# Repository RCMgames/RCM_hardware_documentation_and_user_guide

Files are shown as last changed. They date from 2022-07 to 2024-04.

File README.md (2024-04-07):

RCM User Guide: documentation of the pinout of the RCM board.

Robot Control Module: instructions and CAD for the original 3 versions of RCM boards.

## RCM_ORIGINAL

power with 5 NiMH AA batteries



[new robot code](https://github.com/RCMgames/RCMv2)

[new driver station](https://github.com/RCMgames/RCMDS-new)

[old robot code](https://github.com/RCMgames/RCM)

[old driverstation](https://github.com/RCMgames/RCMDS)

See https://github.com/RCMgames/RCM-Hardware-BYTE and https://github.com/RCMgames/RCM-Hardware-Nibble for more advanced Robot Control Modules.

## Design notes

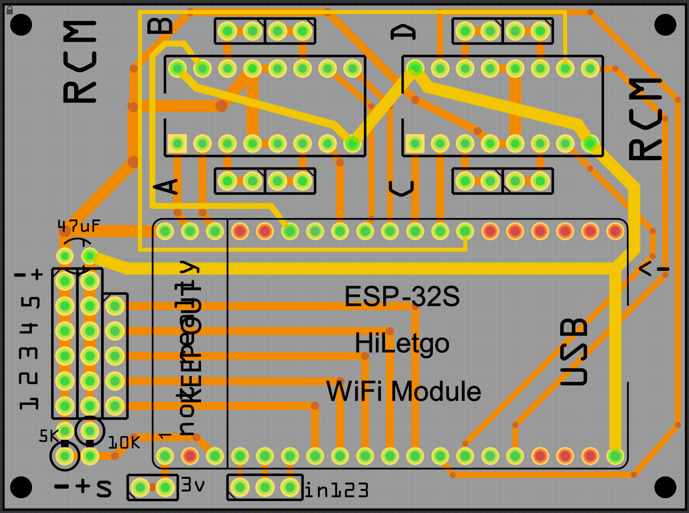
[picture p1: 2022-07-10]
Robot Control Module/V3/circuit diagram and fritzing design/images/image.png

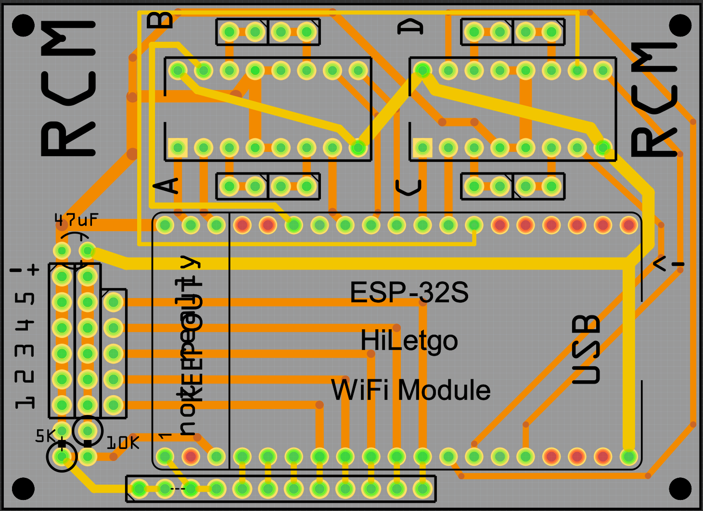
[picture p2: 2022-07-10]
Robot Control Module/V3/circuit diagram and fritzing design/images/Screenshot 2021-02-08 134622.png

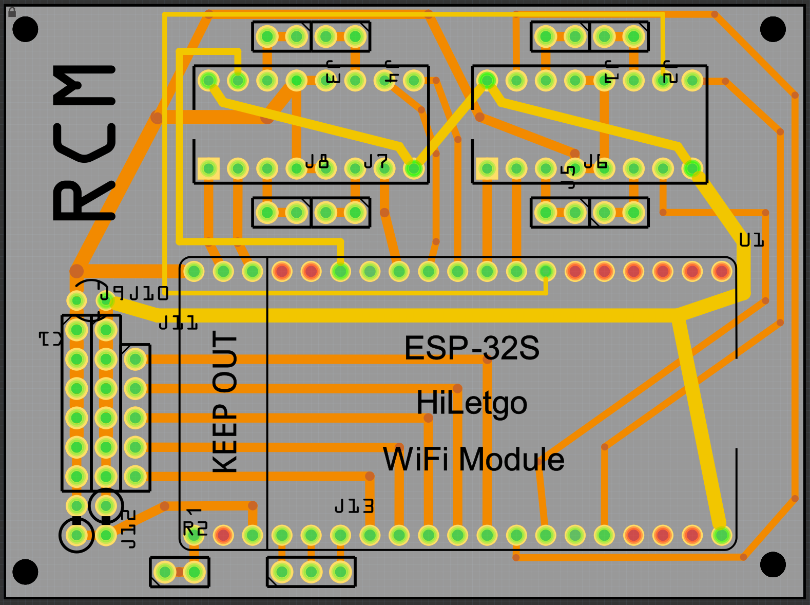
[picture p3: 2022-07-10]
Robot Control Module/V3/circuit diagram and fritzing design/images/Screenshot 2021-02-08 115525.png

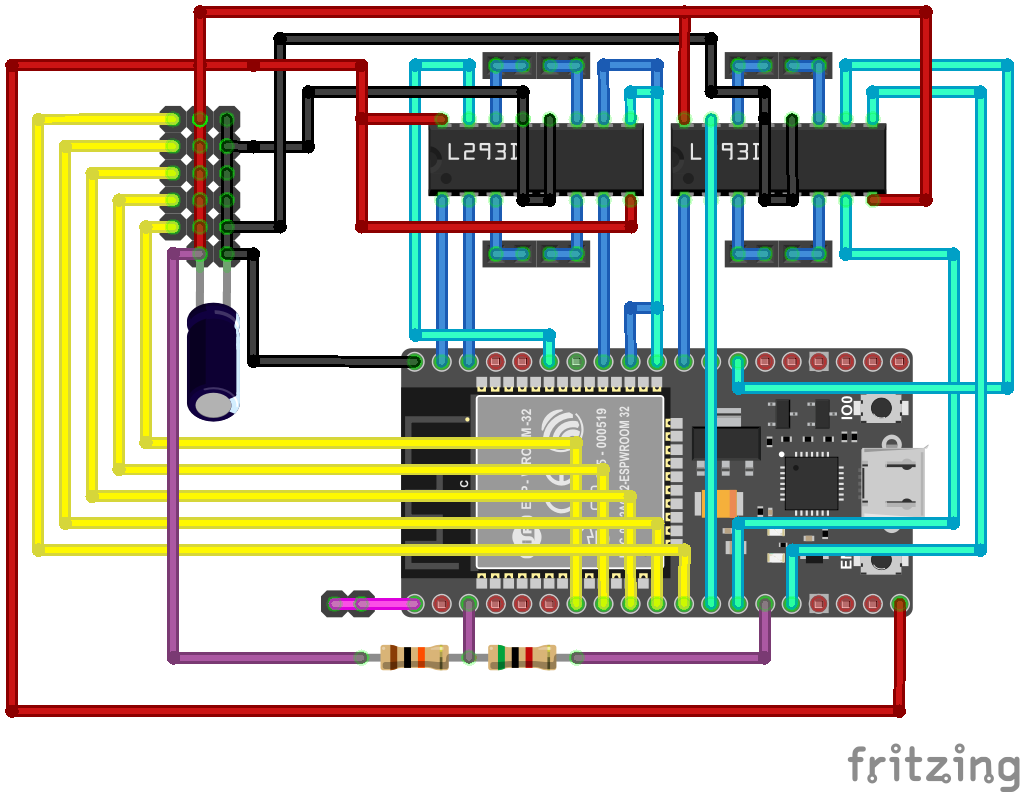
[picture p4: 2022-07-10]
Robot Control Module/V3/circuit diagram and fritzing design/rcm_bb.png

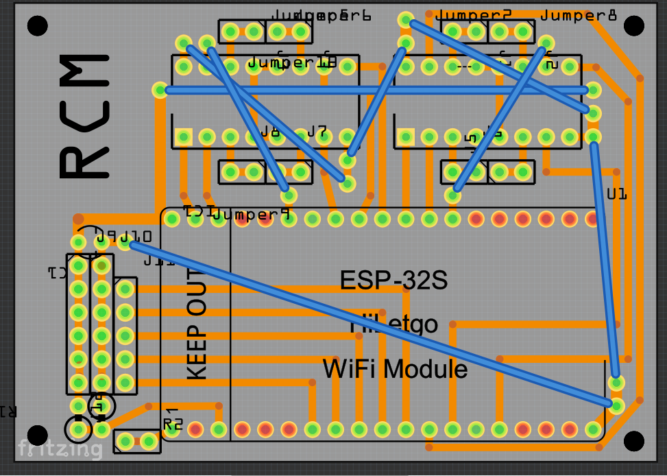
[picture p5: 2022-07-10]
Robot Control Module/other documents/Screenshot 2021-07-22 152102.png

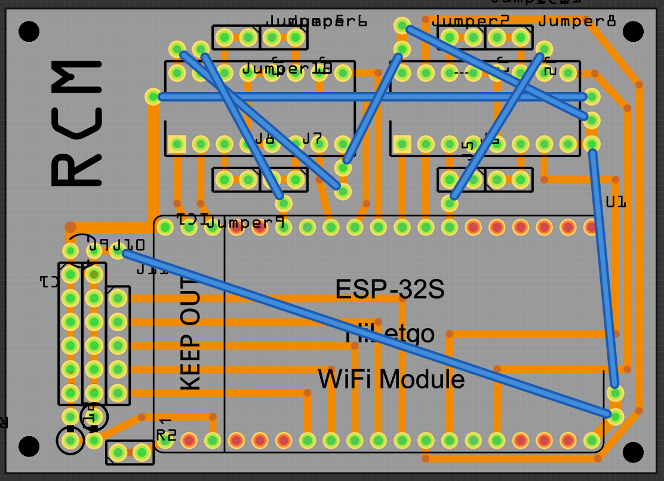
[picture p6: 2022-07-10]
Robot Control Module/other documents/Capture.PNG

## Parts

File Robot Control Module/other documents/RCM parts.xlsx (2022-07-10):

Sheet: parts
Parts for RCM | Part | description | pkg price | enough for | link | alternatives
 | esp32 | processor + wifi | $10.99 | 1 | https://www.amazon.com/dp/B0718T232Z (https://www.amazon.com/HiLetgo-ESP-WROOM-32-Development-Microcontroller-Integrated/dp/B0718T232Z?s=electronics) | 2 for $15 https://www.amazon.com/dp/B07QCP2451
 | L293D | motor driver chip | $7.94 | 5 | https://www.amazon.com/dp/B07BV5R2FY (https://www.amazon.com/Luckkyme-Stepper-Drivers-Controllers-Control/dp/B07BV5R2FY?s=electronics)
 | perf board | hold the parts | $7.99 | 20 | https://www.amazon.com/dp/B07XYL451Y (https://www.amazon.com/AiTrip-Perfboard-Breadboard-Prototyping-Electronic/dp/B07XYL451Y?s=industrial) | custom PCB
 | headers | external ports | $5.99 | 8 | https://www.amazon.com/dp/B074HVBTZ4/
 | 16pin IC sockets | l293d socket
 | wire | 22 gauge or thicker solid core wire recommended | $7.99 | >~5 | https://www.amazon.com/dp/B08979VWP5 (https://www.amazon.com/NorthPada-Electronic-Electrical-Tinned-Voltage/dp/B08979VWP5?s=industrial)
 | capacitors | for esp32 regulator | $5.58 | 10 | https://www.amazon.com/dp/B07KPWC3PB
 | 5K and 10K resistor |  | 8 | 20 | https://www.amazon.com/dp/B0792M83JH
Parts required for a robot
 | power switch |  | $5.99 | 16 | https://www.amazon.com/dp/B0817QGXL2 (https://www.amazon.com/Jabinco-Solder-Rocker-Switch-Toggle/dp/B0817QGXL2)
 | 5 AA battery holder |  | $7.99 | 2 | https://www.amazon.com/dp/B07WRQ44YK
 | 5 NiMH AA batteries
 | battery charger
 | micro usb cable | for programming
----------------------------------------------------------------------------------------------------------------------------------------------------------------------------------------------------------------------------------------------------------------------------------------------------------------------------------------------------------------------------------------------------
 | part type | specific part | pkg price | quantity | link
Misc
 | servo extension cable | jumper wires | $6.98 | 26 | https://www.amazon.com/gp/product/B01EV70C78
Actuators
 | motors
 |  | geared motors with wheels | $14.99 | 4 | https://www.amazon.com/dp/B07DQGX369
 | absolute position servos
 |  | micro servo | $7.99 | 2 | https://www.amazon.com/dp/B07NKRLL5C (https://www.amazon.com/DGZZI-Micro-Replacement-Helicopter-Airplane/dp/B07NKRLL5C?s=toys-and-games)
 |  | medium servo | $15.89 | 2 | https://www.amazon.com/dp/B0881W548Z (https://www.amazon.com/Youleke-MG996R-Metal-Torque-Digital/dp/B0881W548Z?s=toys-and-games)
 | continuous rotation servos
 |  | 9g servo | $13.79 | 2 | https://www.amazon.com/dp/B086ZGTLZB (https://www.amazon.com/Feetech-Continuous-Rotation-Arduino-Microbit/dp/B086ZGTLZB?s=toys-and-games)
Hardware
 | ball casters |  | $9.89 | 6 | https://www.amazon.com/dp/B07HC3Z56Z (https://www.amazon.com/DGQ-Transfers-Furniture-Trolley-Mounted/dp/B07HC3Z56Z)
 | omni wheels |  | $6.84 | 1 | https://www.robotshop.com/en/58mm-plastic-omni-wheel-compatible-servos-lego-mindstorms-nxt.html
 | mechanum wheels |  | $28.59 | 4 | https://www.amazon.com/dp/B082WY3M8G (https://www.amazon.com/Hideness-Mecanum-Connector-Raspberry-Microbit/dp/B082WY3M8G)
 | Makeblock parts are amazing! they have 4mm ID 8mm OD barrings and other things that are helpful if you don't mind trading speed/weight for design complexity
Sensors
 | IR proximity sensors |  | $5.39 | 5 | https://www.amazon.com/dp/B00XAGSWR4
 | limit switches
Gamepieces
 | mini powerup | 1" wooden cubes | $15.99 | 120 | https://www.amazon.com/dp/B072VZFYFC (https://www.amazon.com/Supla-120pcs-Natural-Wooden-Unfinished/dp/B072VZFYFC)

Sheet: Copy of parts
part | description | num needed |  | pkg price | num in pkg | link |  | pkg price | num in pkg | link | <amazon links
esp32 | processor + wifi | 1 | $4.52 | $4.52 | 1 | https://www.aliexpress.com/item/32858054775.html | $8.00 | $15.99 | 2 | https://www.amazon.com/dp/B07QCP2451/
L293D | motor driver chip | 2 | $0.30 | $1.48 | 10 | https://www.aliexpress.com/item/32260501846.html | $1.80 | $8.99 | 10 | https://www.amazon.com/dp/B00ODQM8KC
perf board | hold the parts | 1 | $0.16 | $3.15 | 20 | https://www.aliexpress.com/item/4000742310134.html | $0.47 | $9.50 | 20 | https://www.amazon.com/dp/B072Q1H6GX/
male headers | external ports | 35 | $0.17 | $1.90 | 400 | https://www.aliexpress.com/item/32724478308.html | $0.35 | $5.99 | 600 | https://www.amazon.com/dp/B074HVBTZ4/
female headers | plug for esp32, regulator, capacitors | 49 |  | " | 400 | " | $0.35 | " | 600 | "
16pin IC sockets | l293d socket | 2 | $0.12 | $2.94 | 50 | https://www.aliexpress.com/item/32344551607.html | $0.40 | $5.99 | 30 | https://www.amazon.com/dp/B0079SM1LW/
3d printed shell |  |  |  | - | -
wire |  |  |  | - | -
5 AA bat holder |  | 1 | $1.63 | $1.63 | 1 | https://www.aliexpress.com/item/4000105309247.html | $3.50 | $6.99 | 2 | https://www.amazon.com/dp/B07WRQ44YK
capacitors | for esp32 regulator | 1 | $0.04 | $2.17 | 50 | https://www.aliexpress.com/item/32911921657.html | $0.56 | $5.58 | 10 | https://www.amazon.com/dp/B07KPWC3PB
drive motors | geared motors with wheels | 2 | $2.25 | $4.51 | 4 | https://www.aliexpress.com/item/4000126948489.html | $7.50 | $14.99 | 4 | https://www.amazon.com/dp/B07DQGX369
servos |  | 2 | $2.12 | $10.60 | 10 | https://www.aliexpress.com/item/33009883276.html | $3.80 | $18.99 | 10 | https://www.amazon.com/dp/B072V529YD
5K resistor |  | 1
10K resistor |  | 1
 |  |  | $11.31 |  |  |  | $26.71

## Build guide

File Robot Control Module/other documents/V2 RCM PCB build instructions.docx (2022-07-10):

# Build Instructions for Robot Control Module

Using an ESP-32 processor and L293D motor driver chips

# Design:

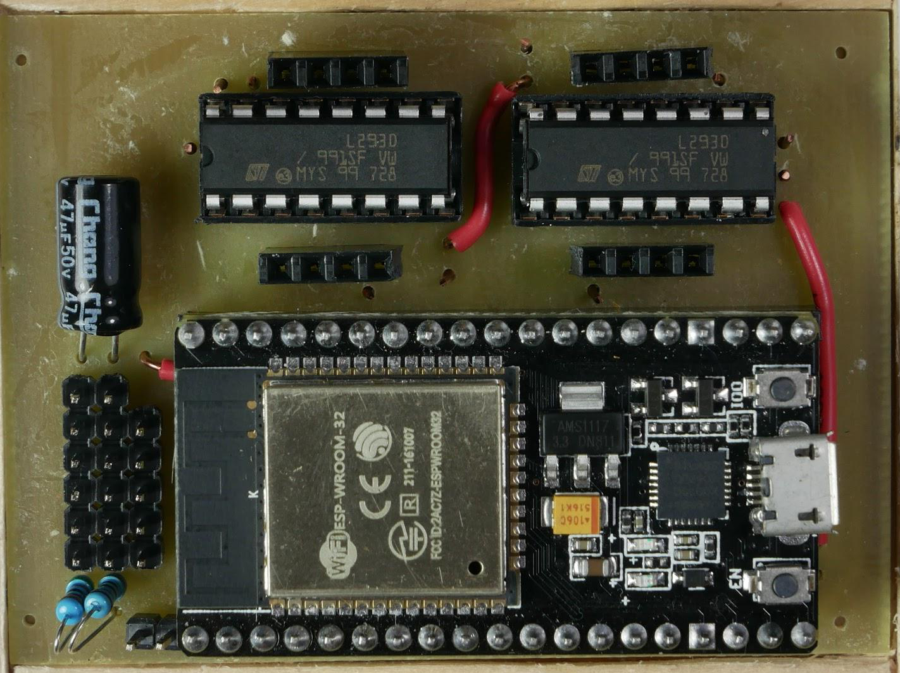
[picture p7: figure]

Top view of finished board

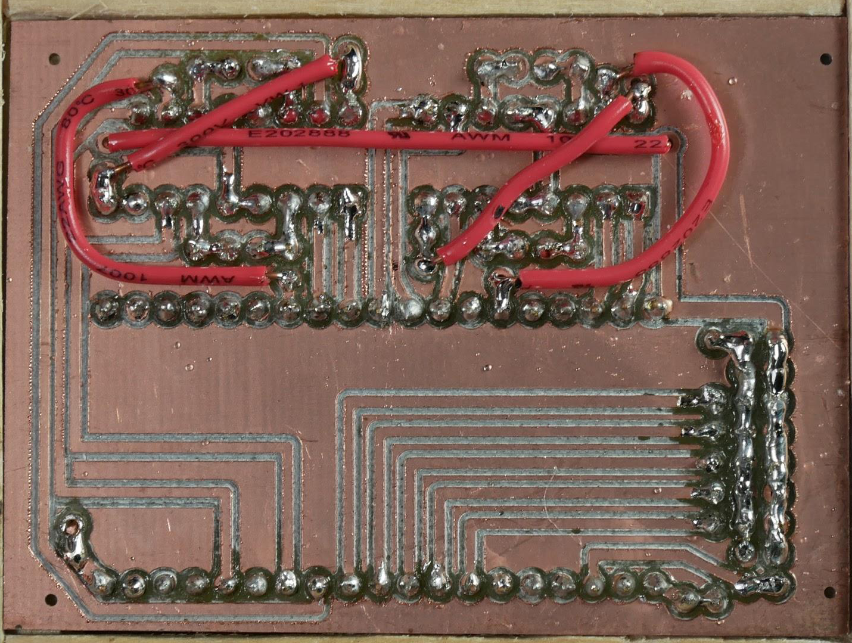
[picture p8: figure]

Bottom view of finished board (flipped like turning a page)


This picture shows the connections of the board. This is a top view of the board but shows the traces as if the board were see through.

# Parts:

1 NodeMCU ESP-32s, it should have 38 pins

2 L293D motor driver chip

1 custom circuit board

56 female header pins

19 male header pins

2 16 pin IC sockets

4ft wire (I used 22 gauge solid core)

1 5 AA bat holder

1 47uf capacitor

1 5 KΩ resistor

1 10 KΩ resistor

0-4 small 6v geared motors (<600 mA)

0-5 micro servo motors

5 rechargeable NiMH AA batteries

# Tools:

Soldering iron

Solder

Needle nose pliers

Wire strippers

Flush cutters

Sandpaper

Fume extractor fan

Tape

# Custom Circuit Board:

Here is the fritzing file for the board: https://drive.google.com/open?id=1aipQb9t6Qfr8hrADWvjOZhG9OkPFuLrj

When exporting for your router or circuit board service, make sure that the board will end up like in the photo below and not mirrored or with the traces on the wrong side of the board.

# Build:

Check the metal side of the board and make sure there are no shorts across traces or “stringy” bits of metal.

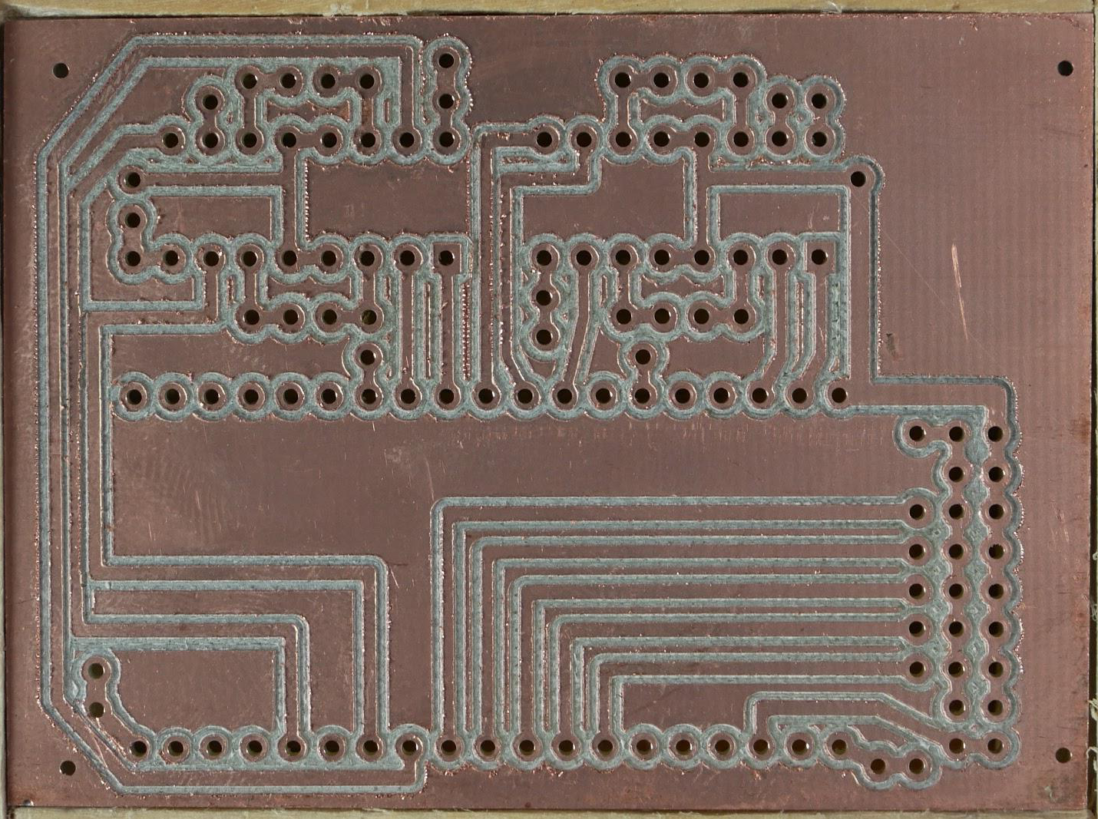
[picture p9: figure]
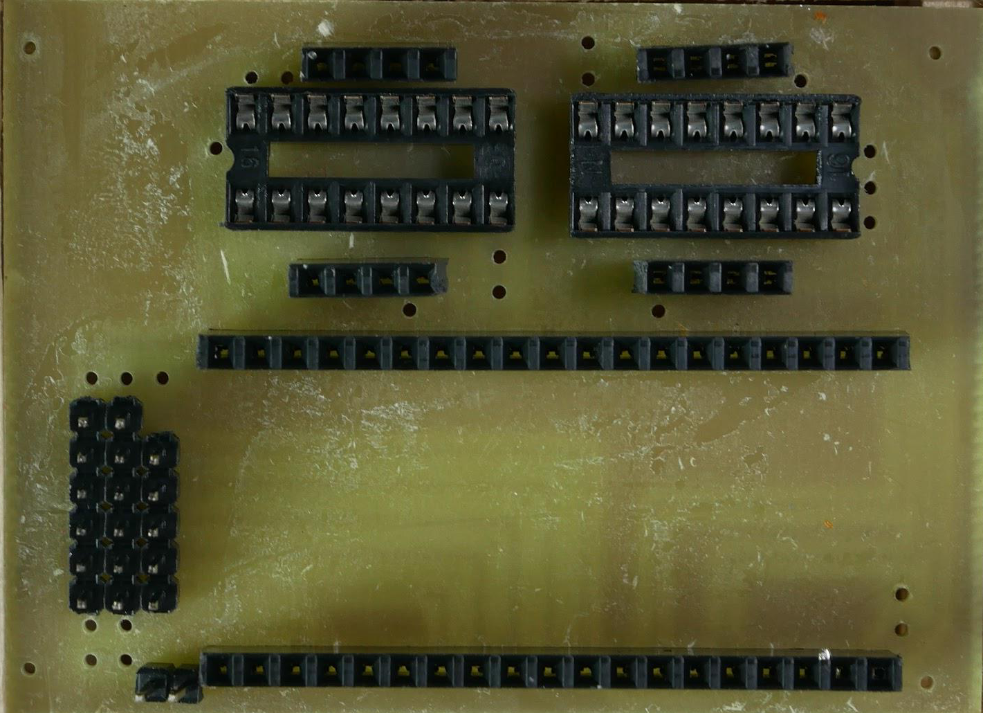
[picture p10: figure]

Place components in the board as shown.

Use tape to secure each part to the board so it won’t fall out when you turn the board over to solder. Make sure everything stays at right angles to the board since if pins are soldered at an angle it will be hard to plug into them later.

Solder every pin to the board.

If two pins get bridged by solder that aren’t connected with a copper trace, you need to disconnect them (try melting the bridge with the soldering iron and “cutting” the blob with the tip of the iron.

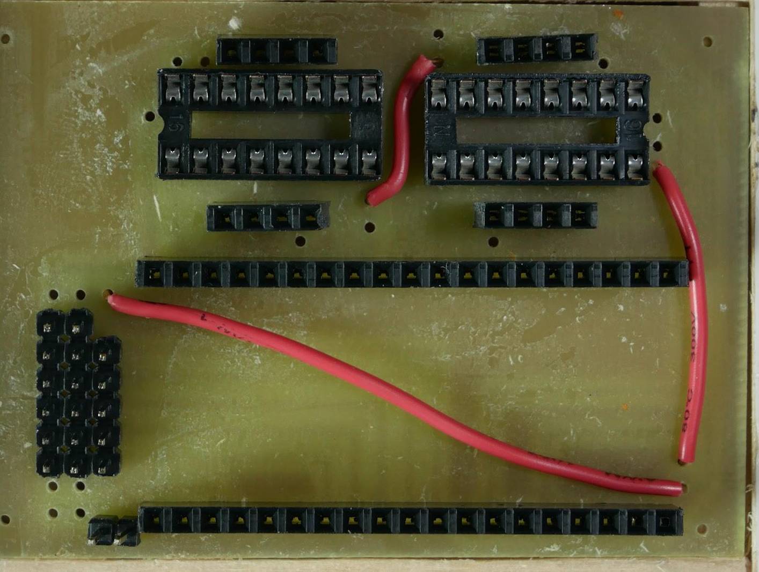
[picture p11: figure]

Add three wires to the top of the board as shown.

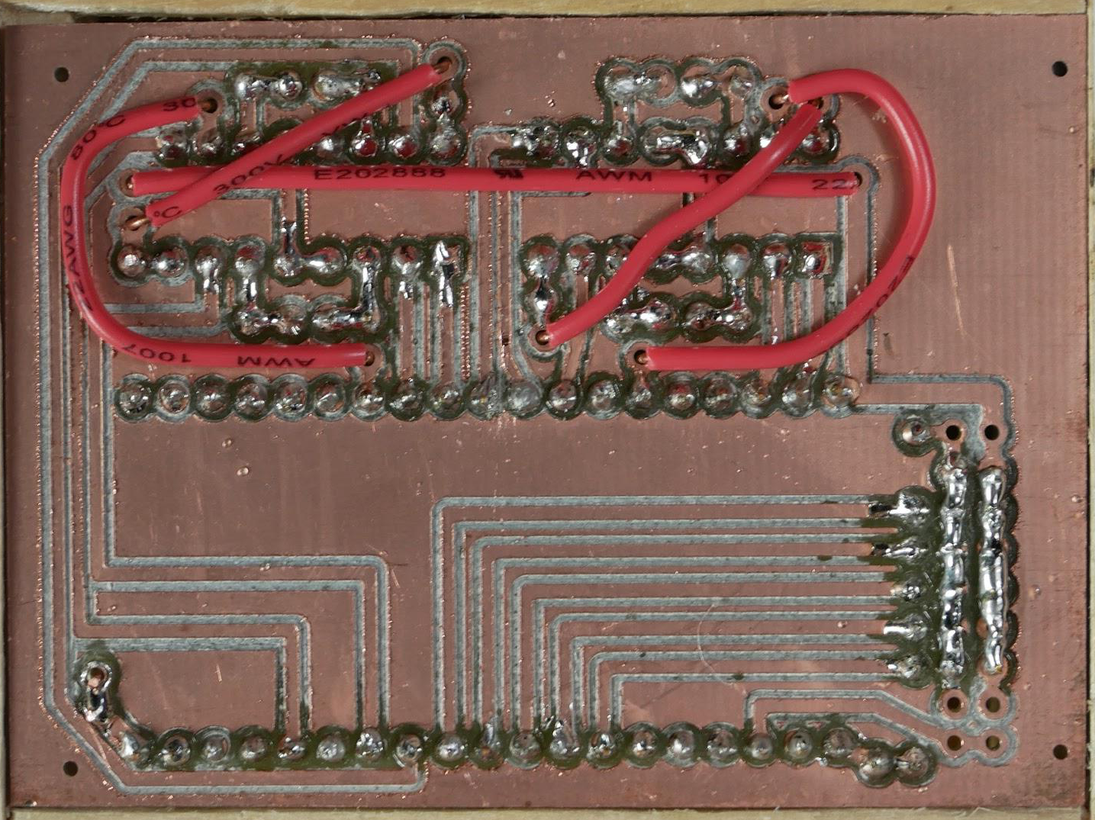
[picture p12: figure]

Add 5 wires to the bottom of the board as shown. Leave a little uninsulated wire out of the hole so you can add solder.

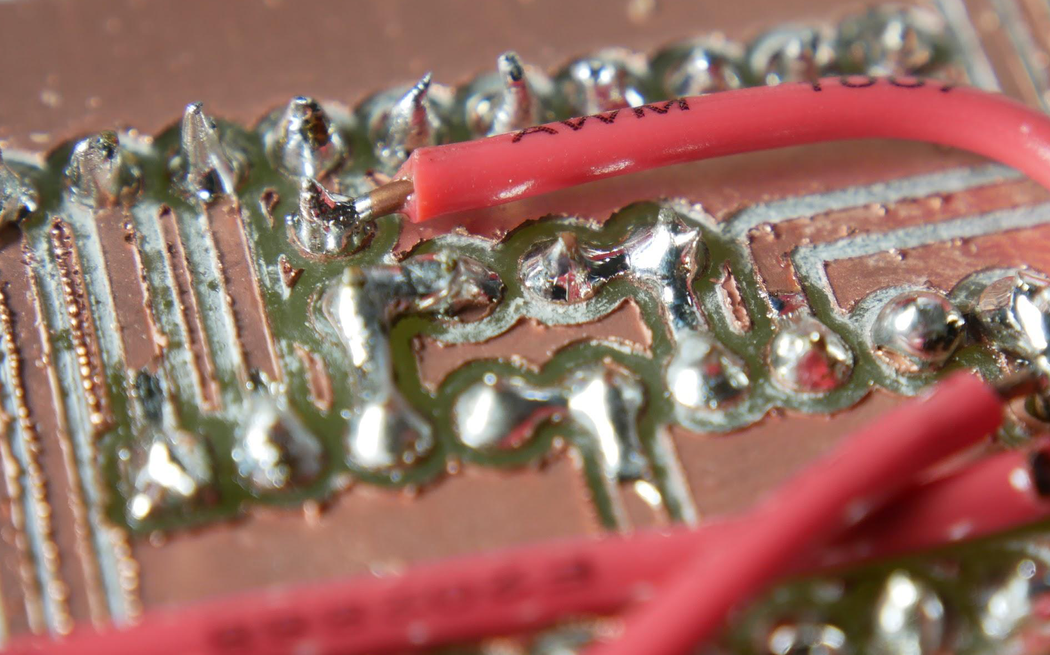
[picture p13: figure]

Solder all the wires in.

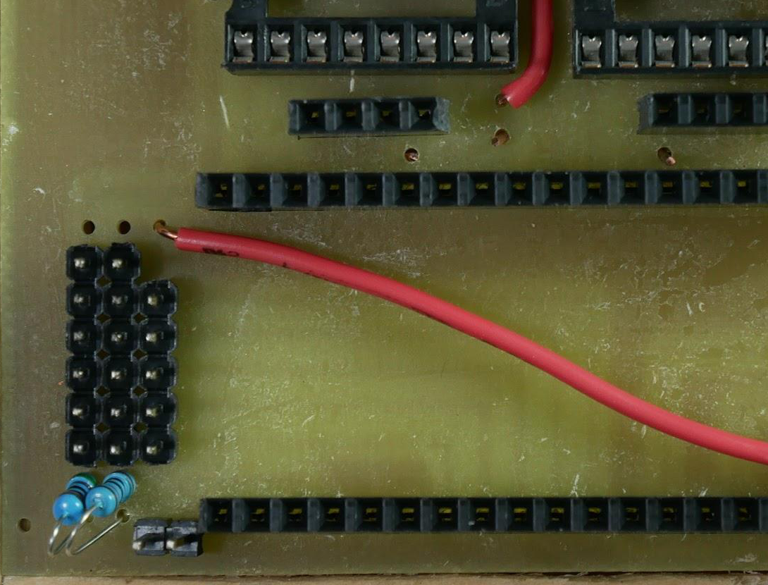
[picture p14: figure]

Solder the two resistors to the board as shown in the picture. The resistor on the left should be 5 KΩ and the one on the right should be 10 KΩ.

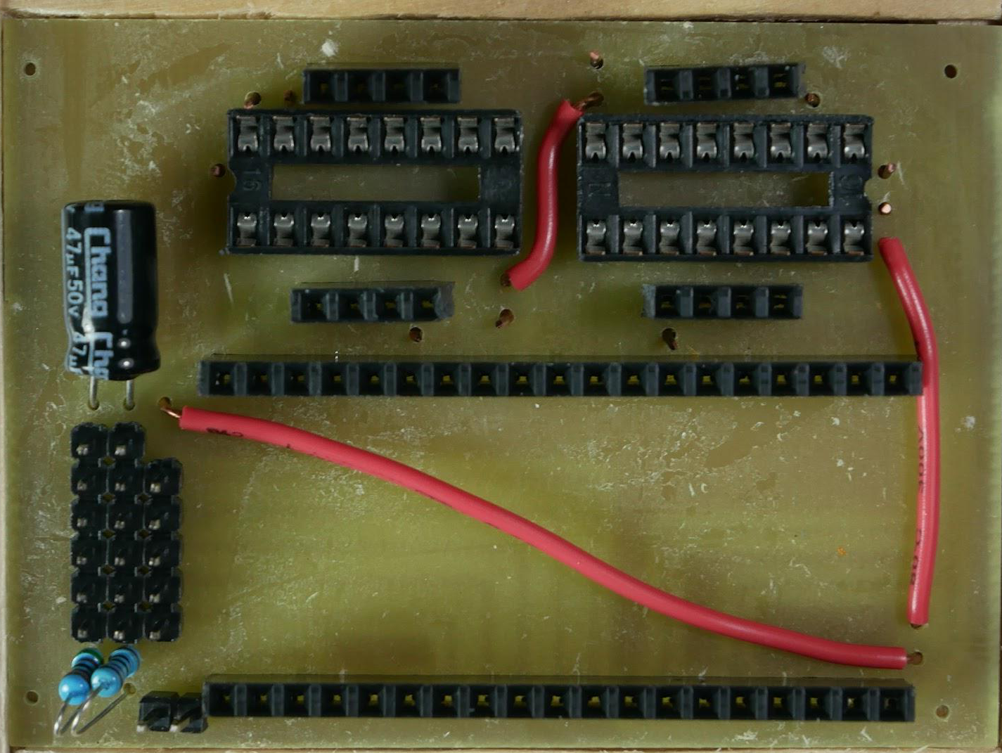
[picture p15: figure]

Solder the 47 uF capacitor to the board as shown in the picture. The negative wire of the capacitor (it’s on the side marked with a stripe, and it’s the shorter wire) needs to go in the left hole.

Trim any wires or pins that stick out too far from the board.

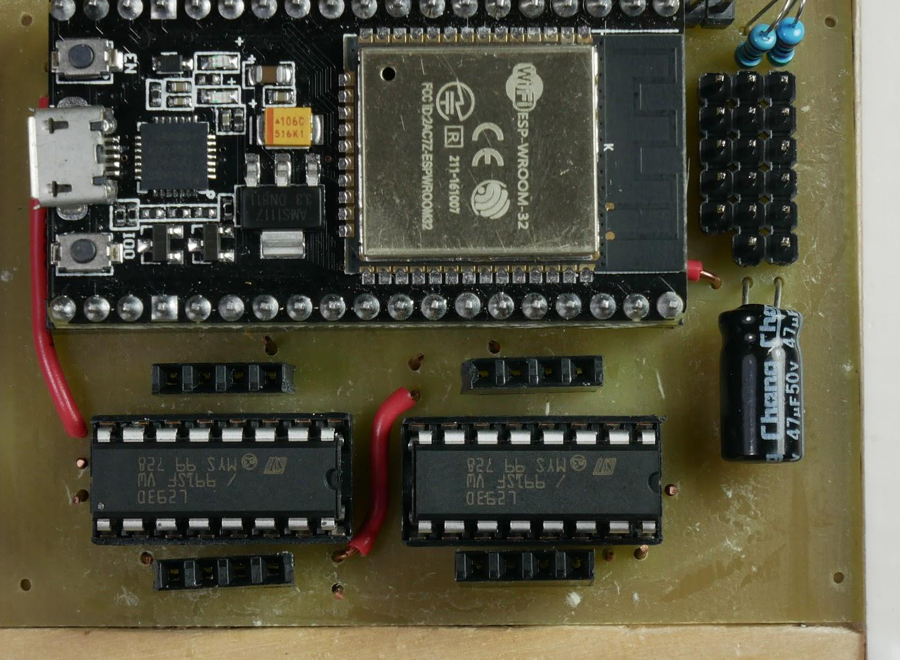
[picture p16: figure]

Add the ESP32 and the L293D chips. The orientation of the ESP32 should be as in the photo, the orientation of the driver chips doesn’t matter.

Add female pins to the battery pack wires.

Solder solid core wire or male headers to the motors so they can be plugged in.

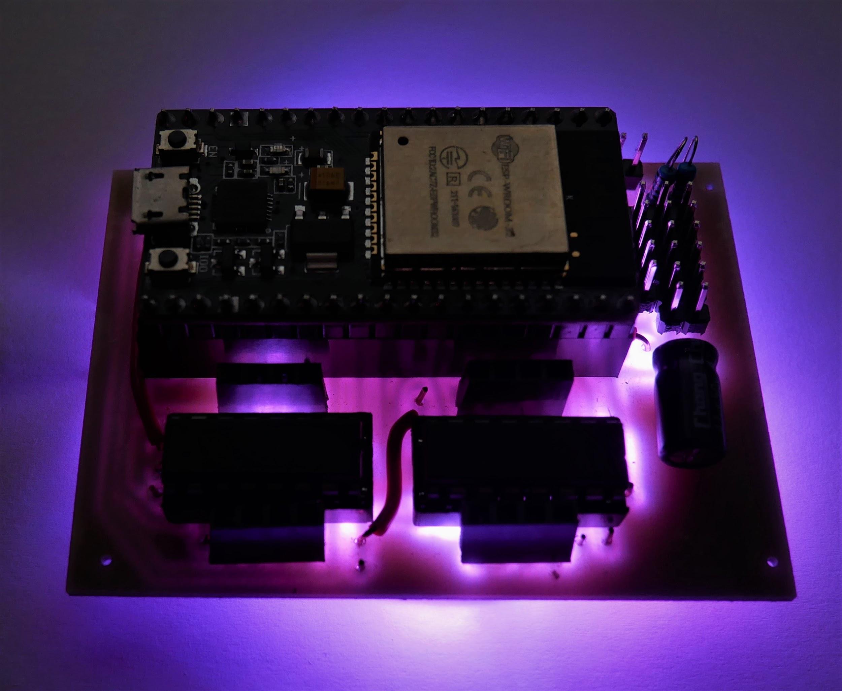
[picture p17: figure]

YOU’RE DONE BUILDING THE RCM!

# Programming:

## Upload Code to RCM:

https://github.com/rcmgames/rcm

## Install Driver Station App:

https://github.com/rcmgames/RCMDS

https://github.com/rcmgames/RCMDS-new

RCM user guide (https://drive.google.com/open?id=12HUcpWKluF6-3oLMwZiLKZ4KrxwmTE_D)

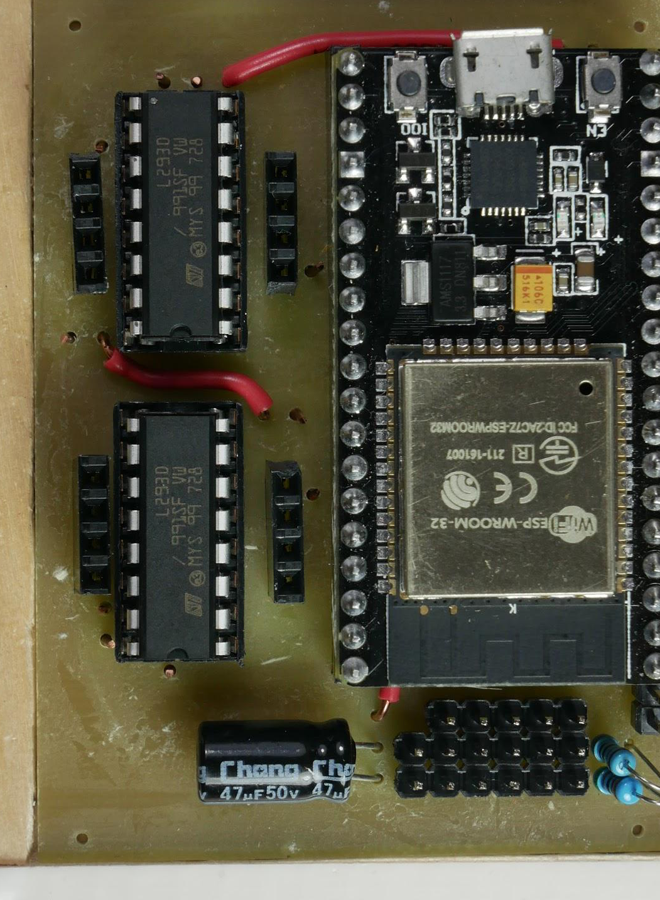
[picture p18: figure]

When the board is oriented as shown in the picture above:

the motor ports are called:

portA portB

portC portD

(put one motor wire in one of the top two holes, one wire in one of the bottom two holes)

the servo ports are called:

port1 port2 port3 port4 port5

(plug servos in with ground at the top)

The power connection is to the right of the servo ports, ground is on top, +V is below that (don’t reverse).

The button to the right of the USB plug should be pressed when the Arduino IDE starts connecting to the esp32 or the upload will fail.

The button to the left of the USB plug restarts the code running on the esp32, you can try pressing it if you lose connection.

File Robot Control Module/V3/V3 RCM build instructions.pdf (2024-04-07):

## Build Instructions for Robot Control Module

### Using an ESP32 processor and L293D motor driver ICs

## Design:

Top view of finished board

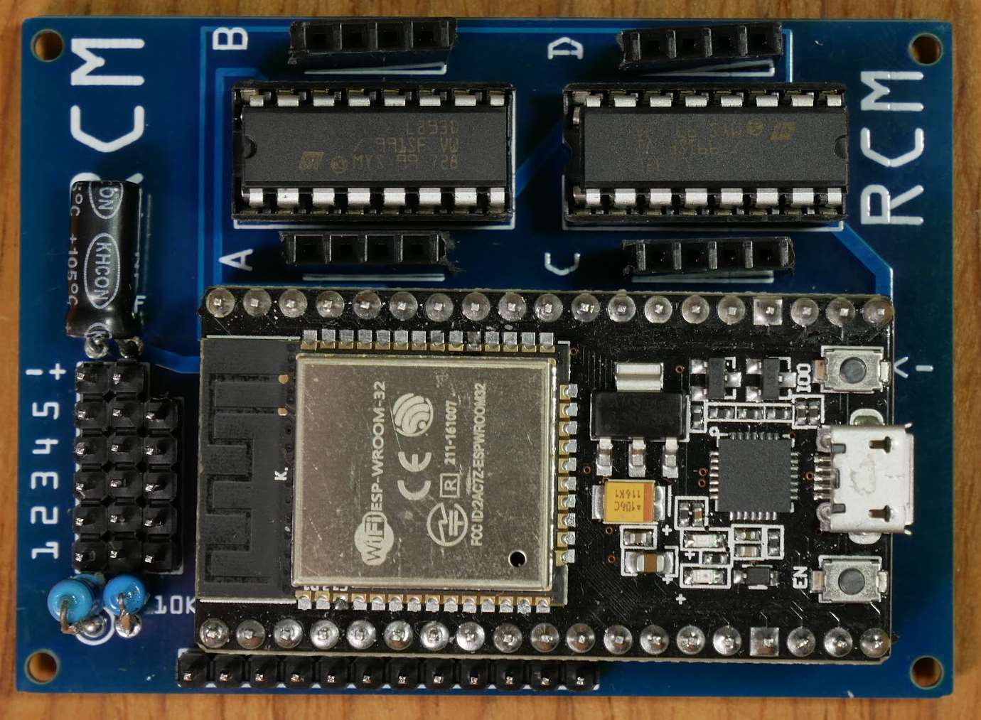
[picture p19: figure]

Bottom view of finished board (flipped like turning a page)

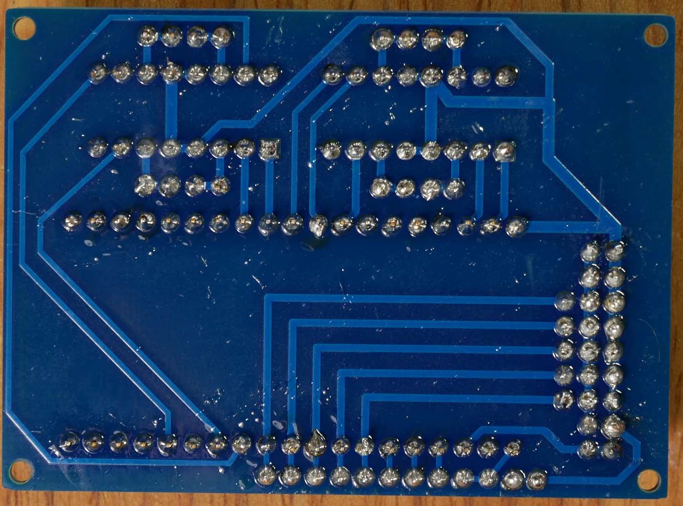
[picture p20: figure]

This picture shows the connections of the board. This is a top view of the board but shows the traces as if the board were see through.

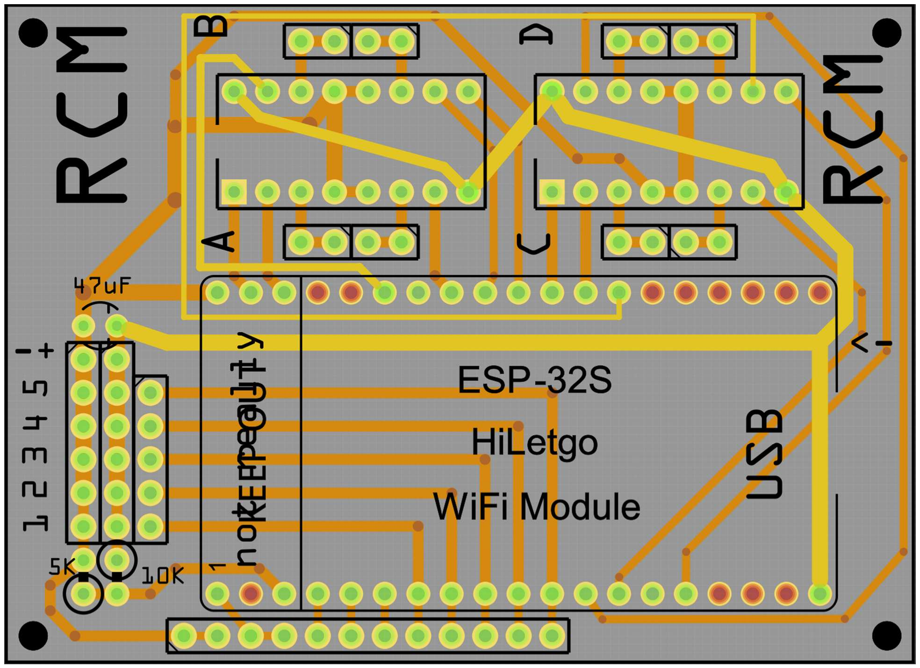
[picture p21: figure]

Parts:

### 1 NodeMCU ESP-32s, it should have 38 pins 2 L293D motor driver chip 1 custom two layer circuit board

2x19,4x4 | female header pins (quantity X number pins)
1x12,2x6,1x5 | male header pins
2 16 pin IC sockets
1 47uf capacitor
1 5 KΩ resistor
1 10 KΩ resistor
0-4 | small 6v geared motors (<600 mA)

0-5 | micro servo motors

### 5 rechargeable NiMH AA batteries

1 5 AA bat holder

### 1 small switch for turning power on and off

Tools:

Soldering iron
Solder
Needle nose pliers
Wire strippers
Flush cutters
Sandpaper (for sanding down edges of cut header pieces) Fume extractor fan
Tape

Custom Circuit Board:

Here is the fritzing file for the board, and here are the exported gerber files for the board.
When exporting for your router or custom pcb service, make sure that the board will end up like in the photos above and not mirrored.

Build:

Orient the circuit board as shown.

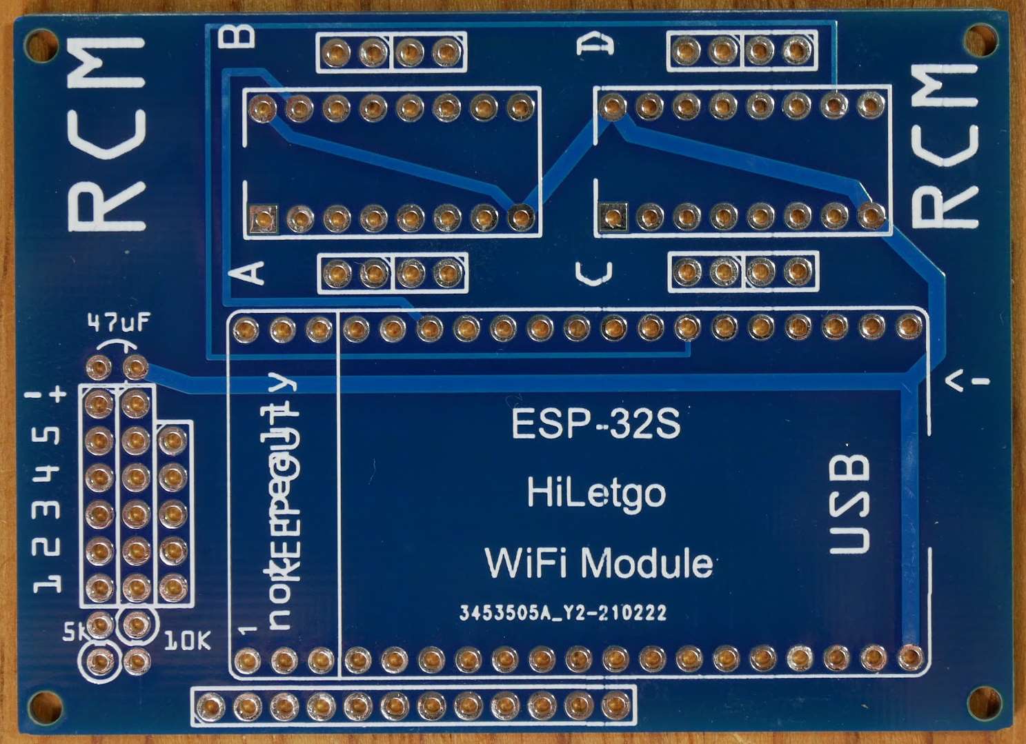
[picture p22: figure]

Solder the two resistors to the board as shown in the picture. The resistor on the left should be 5 KΩ and the one on the right should be 10 KΩ.
[picture]

Solder the 47 uF capacitor to the board as shown in the picture. The negative wire of the capacitor (it’s on the side marked with a stripe, and it’s the shorter wire) needs to go in the left hole.

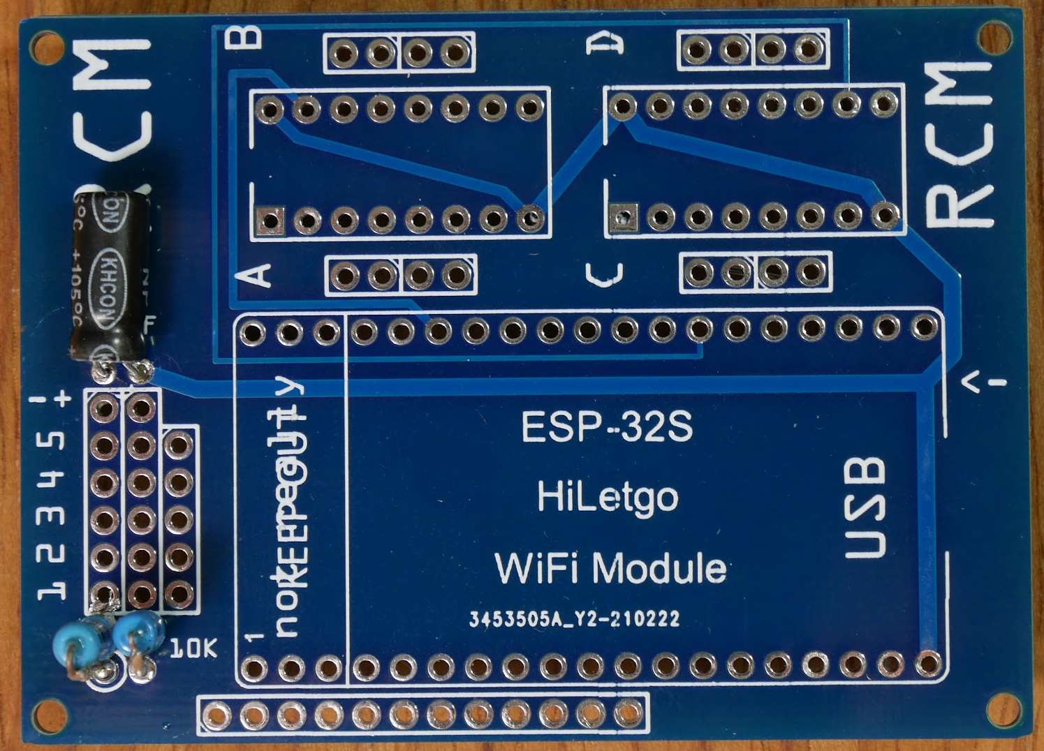
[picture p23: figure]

Use tape to secure each part to the board so it won’t fall out when you turn the board over to solder. Make sure everything stays at right angles and flush to the board since if pins are soldered at an angle it will be hard to plug into them later. You can place and solder parts one at a time if you find that easier.

Place the remaining components in the board as shown below and solder every pin.

It may be easiest to first add the 2 16 pin sockets and all male pins, then add all 4 sets of 4 female pins, and finally add the 2 large strips of female headers which hold the esp32.

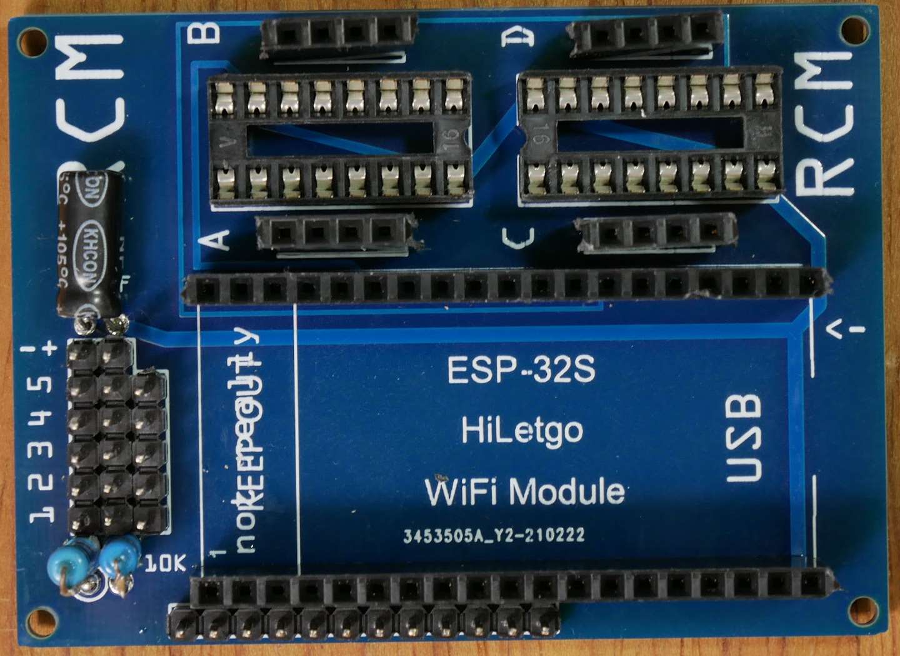
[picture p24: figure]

If two pins get bridged by solder that aren’t connected with a copper (lighter color showing through board color) trace, you need to disconnect them (try melting the bridge with the soldering iron and “cutting” the blob with the tip of the iron.

Trim any wires or pins that stick out too far on the back.

Plug in the ESP32 and the L293D chips. The orientation of the ESP32 should be as in the photo, the orientation of the driver chips doesn’t matter.

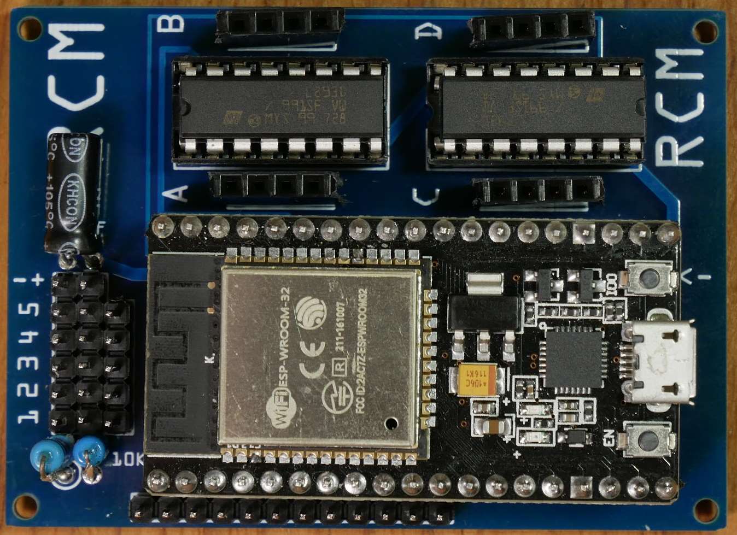
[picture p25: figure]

Add female pins to the battery pack wires and add the power switch to one of the wires.
[picture]

Solder solid core wire or male headers to the motors so they can be plugged in.

[picture?]

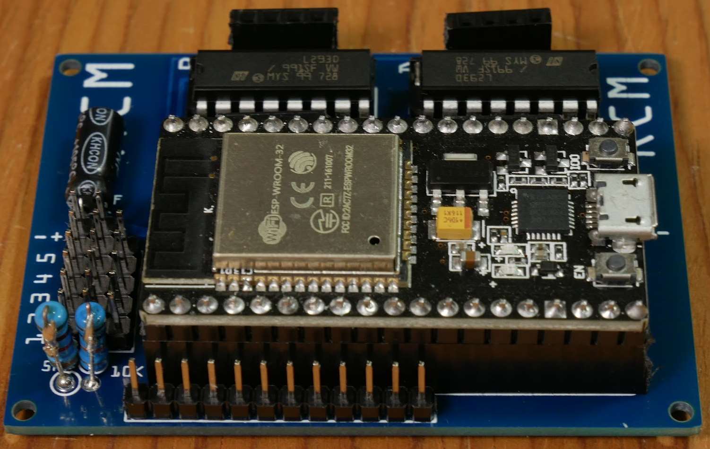
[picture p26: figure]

YOU’RE DONE BUILDING THE RCM!

Programming:
Upload Code to RCM:
https://github.com/rcmgames/rcm (look at branches for examples)

Install Driver Station App:
https://github.com/rcmgames/RCMDS-new (recommended) https://github.com/rcmgames/RCMDS (advanced)

# RCM user guide

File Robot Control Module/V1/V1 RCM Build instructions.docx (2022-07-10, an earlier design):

# Build Instructions for Robot Control Module

Using an ESP-32 processor and L293D motor driver chips

# Design:

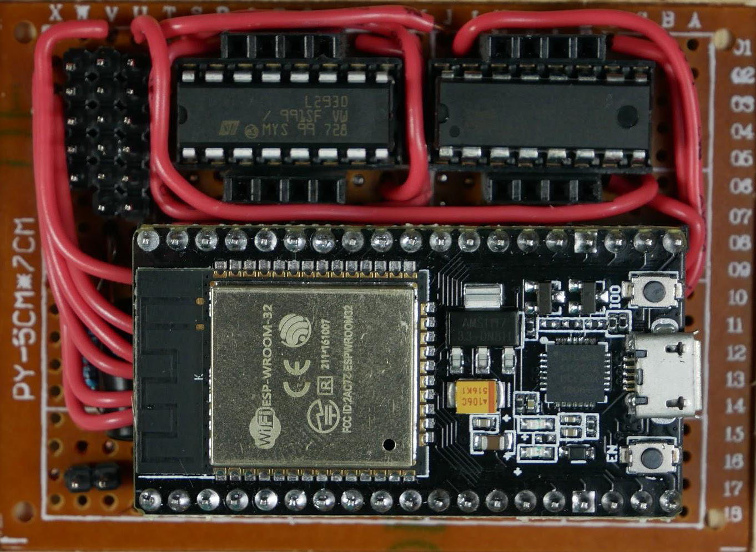
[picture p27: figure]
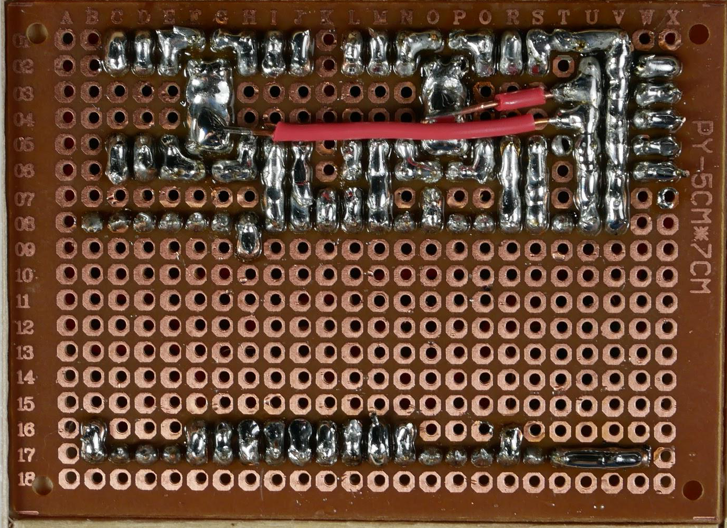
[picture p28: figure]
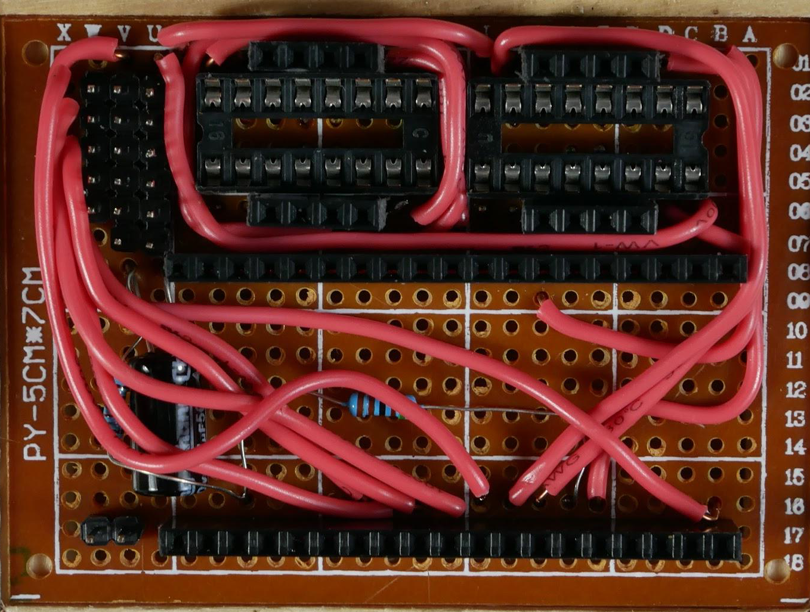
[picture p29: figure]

Spreadsheet of circuit design. (https://docs.google.com/spreadsheets/d/1CU-nc-A7mxIIo_vOU9j2zoCkf-lnWo5c/edit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)


# Parts:

1 NodeMCU ESP-32s, it should have 38 pins

2 L293D motor driver chip

1 2x3 inch perf board with 18x24 holes

54 female header pins

19 male header pins

2 16 pin IC sockets

4ft wire (I used 22 gauge solid core)

1 5 AA bat holder

1 47uf capacitor

1 5 KΩ resistor

1 10 KΩ resistor

0-4 small 6v geared motors (<600 mA)

0-5 micro servo motors

5 rechargeable NiMH AA batteries

# Tools:

Soldering iron

Solder

Needle nose pliers

Wire strippers

Flush cutters

Sandpaper

Fume extractor fan

Tape

# Build:

## Add components

1. Notice the letter and number labels on the perf board. Orient the perfboard so 1 corresponds to the top row of holes, 18 corresponds to the bottom row, A corresponds to the right column and X corresponds to the left. This is the side components will be added from. Only add components to the side without metal around the holes, only solder to the side with metal around the holes.
2. Use tape to secure each part to the board so it won’t fall out when you turn the board over to solder. Make sure everything stays at right angles to the board since if pins are soldered at an angle it will be hard to plug into them later.
3. Cut two 19 pin strips of female headers and put them in the board so they fill holes 8B-8T and 17B-17T. Solder each pin to its hole.
4. Solder one 16 pin socket into holes 2C-2J and 5C-5J and solder the other socket into holes 2L-2S and 5L-5S.
5. Solder 1 strip of 5 male header pins in 2W-6W, and 2 strips of 6 male header pins in 2V-7V and 2U-7U.
6. Solder 4 strips of 4 female headers in the following holes: 1E-1H, 6E-6H, 1N-1Q, 6N-6Q.
7. Solder two male headers in holes 17V and 17W
8. Put the negative wire of the capacitor (marked with a grey stripe and the shorter of the two) in 8U. Put the other wire of the capacitor and one wire of the 10KΩ resistor in 8V. The capacitor’s leads should be long enough that it can be laid down on the board (~1cm), and the resistor’s wire should be about 2 cm. Solder the parts in.
9. Solder one wire of the 5KΩ resistor to 16G leaving the wire about 2 cm long.
10. Solder the free wires of the two resistors to 16R. Make sure to not block the holes in row 16 with the resistor wire since other wires will need to connect there.
11. Trim any long wires sticking out of the solder.

## Make connections

12. Flip the board to the component side.
13. To connect two holes with a wire, cut a length of wire slightly longer than the distance between the two holes, strip about 2 mm of insulation off both ends, and put the ends in the holes. Try to route the wires nicely and remember that you’ll need to be able to access the plugs.
14. Connect holes 1L and 7K with a wire.
15. Connect holes 1M and 7L with a wire.
16. Connect holes 1R and 7O with a wire.
17. Connect holes 1C and 16F with a wire.
18. Connect holes 1D and 9H with a wire.
19. Connect holes 6D and 16H with a wire.
20. Connect holes 1I and 16I with a wire.
21. Connect holes 1S and 6L with a wire.
22. Connect holes 1T and 1J with a wire.
23. Connect holes 1U and 6C with a wire.
24. Connect holes 1V and 16B with a wire.
25. Connect holes 6X and 16N with a wire.
26. Connect holes 5X and 16M with a wire.
27. Connect holes 4X and 16L with a wire.
28. Connect holes 3X and 16K with a wire.
29. Connect holes 2X and 16J with a wire.
30. Flip the board over to the back side and solder all the wires in.
31. To connect holes over shorter distances, blob solder between them.
32. Connect holes 1C and 2C by bridging them with solder.
33. Connect holes 1D and 2D by bridging them with solder.
34. Connect holes 1I and 2I by bridging them with solder.
35. Connect holes 1J and 2J by bridging them with solder.
36. Connect holes 5C and 6C by bridging them with solder.
37. Connect holes 5D and 6D by bridging them with solder.
38. Connect holes 1L and 2L by bridging them with solder.
39. Connect holes 1M and 2M by bridging them with solder.
40. Connect holes 1R and 2R by bridging them with solder.
41. Connect holes 5L and 6L by bridging them with solder.
42. Connect holes 8H and 9H by bridging them with solder.
43. Connect holes 7K and 8K by bridging them with solder.
44. Connect holes 7L and 8L by bridging them with solder.
45. Connect holes 7O and 8O by bridging them with solder.
46. Connect holes 16B and 17B by bridging them with solder.
47. Connect holes 16F and 17F by bridging them with solder.
48. Connect holes 16G and 17G by bridging them with solder.
49. Connect holes 16H and 17H by bridging them with solder.
50. Connect holes 16I and 17I by bridging them with solder.
51. Connect holes 16J and 17J by bridging them with solder.
52. Connect holes 16K and 17K by bridging them with solder.
53. Connect holes 16L and 17L by bridging them with solder.
54. Connect holes 16M and 17M by bridging them with solder.
55. Connect holes 16N and 17N by bridging them with solder.
56. Connect holes 16R and 17R by bridging them with solder.
57. Connect holes 2W and 2X by bridging them with solder.
58. Connect holes 3W and 3X by bridging them with solder.
59. Connect holes 4W and 4X by bridging them with solder.
60. Connect holes 5W and 5X by bridging them with solder.
61. Connect holes 6W and 6X by bridging them with solder.
62. Connect holes 1E, 2E, and 1F by bridging them with solder.
63. Connect holes 1H, 2H, and 1G by bridging them with solder.
64. Connect holes 5E, 6E, and 6F by bridging them with solder.
65. Connect holes 5H, 6H, and 6G by bridging them with solder.
66. Connect holes 1N, 2N, and 1O by bridging them with solder.
67. Connect holes 1Q, 2Q, and 1P by bridging them with solder.
68. Connect holes 5N, 6N, and 6O by bridging them with solder.
69. Connect holes 5Q, 6Q, and 6P by bridging them with solder.
70. Connect holes 5I-8I by bridging them with solder.
71. Connect holes 5J-8J by bridging them with solder.
72. Connect holes 5M-8M by bridging them with solder.
73. Connect holes 5R-8R by bridging them with solder.
74. Connect holes 5S-8S by bridging them with solder.
75. Connect holes 1V-8V and 1S-1U and 2S by bridging them all with solder.
76. Connect holes 2U-8U, and 8T by bridging them all together with solder.
77. Connect holes 17T-17W by bridging them with solder.
78. Connect holes 2O-5P by bridging them with solder.
79. Connect a wire from 3T to this blob, and also bridge 3T over to 3U (don’t stick the wire in the hole all the way up to the insulation).
80. Connect holes 2F-5G by bridging them with solder.
81. Connect a wire from 4T to this blob, and also bridge 4T over to 4U.
82. Plug the esp32 into the long header strips, so the usb port faces right.
83. Plug the two l293d chips into their sockets, rotation doesn’t matter.

Optional extra 3 input pins

Put 3 male headers in 18O-18Q and bridge each pin to the neighboring pin on row 17.

Viewing the board from the front side, the headers connect to esp32 pins 39, 34, 35 with 35 the closest to the usb port. These pins on the esp32 can only function as inputs!

Power Switch and batteries

Add female pins to the battery pack wires.

Solder solid core wire or male headers to the motors so they can be plugged in.

# Programming and Testing:

RCM user guide (https://drive.google.com/open?id=12HUcpWKluF6-3oLMwZiLKZ4KrxwmTE_D)

## Upload Code to RCM:

https://github.com/rcmgames/rcm

## Install Driver Station App:

https://github.com/rcmgames/RCMDS

https://github.com/rcmgames/RCMDS-new

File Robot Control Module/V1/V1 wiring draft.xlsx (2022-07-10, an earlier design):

 |  | E | F | mh | mh | mh | mh | G | J* |  | B | C | mh | mh | mh | mh | A | J* | J* | J* | P
 |  | en12 | i1 | o1 | gnd | gnd | o2 | i2 | vcc2 |  | en12 | i1 | o1 | gnd | gnd | o2 | i2 | vcc2 |  | gnd | bat | 27 GPIO,PWM | K
 |  |  |  | L | 2 | 9 | 3 | D |  |  |  |  | L | 2 | 9 | 3 | D |  | I | gnd | bat | 26 DAC,GPIO,PWM | L
 |  |  |  | bottom |  | view |  |  |  |  |  |  | bottom |  | view |  |  |  | I | gnd | bat | 25 DAC,GPIO,PWM | M
 |  | vcc1 | i4 | o4 | gnd | gnd | o3 | i3 | en34 |  | vcc1 | i4 | o4 | gnd | gnd | o3 | i3 | en34 |  | gnd | bat | 33 ADC,GPIO,PWM | N
 |  | J* | H | mh | mh | mh | mh |  |  |  | J* |  | mh | mh | mh | mh |  |  |  | gnd | bat | 32 ADC,GPIO,PWM | O
 |  |  |  |  |  |  |  |  |  | B | C |  |  | A |  |  |  |  |  | gnd | bat
 | 6 | 7 | 8 | 15 | 2 | 0 | 4 | 16 | 17 | 5 | 18 | 19 | gnd | 21 | rx0 | tx0 | 22 | 23 | gnd | capacitor 5Kohm
 |  |  |  |  |  |  | F
 |  |  |  | E |  |  |  | S |  |  |  | P |  |  | 3 |  | 2
u
s |  |  |  |  |  | BOTTOM |  |  | VIEW
b
 | P |  |  |  | E | 5K ohm | H | G | K | L | M | N | O |  |  |  | J resistors
 | vin | 11 | 10 | 9 | 13 | gnd | 12 | 14 | 27 | 26 | 25 | 33 | 32 | 35 | 34 | 39 | 36 | en | 3.3v |  | 3.3v | 3.3v
